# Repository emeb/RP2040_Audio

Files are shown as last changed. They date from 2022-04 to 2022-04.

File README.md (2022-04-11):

# RP2040_Audio
A Eurorack module for stereo audio effects based on the Raspberry Pi RP2040 MCU

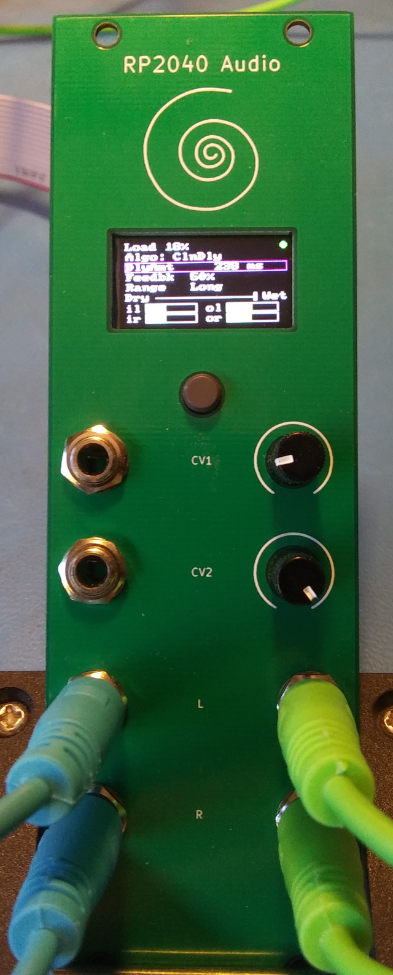
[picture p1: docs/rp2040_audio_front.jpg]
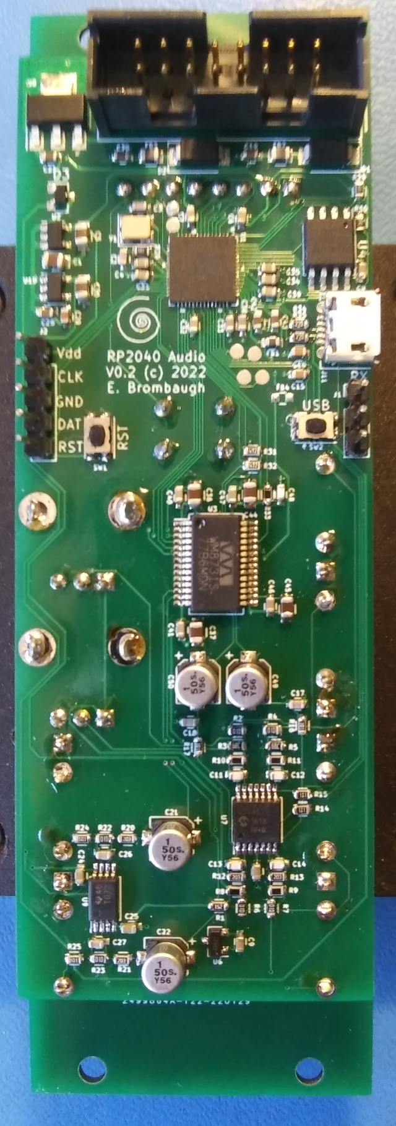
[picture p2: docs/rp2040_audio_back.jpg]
  

## Abstract
I've been doing audio synthesis and effects in the Eurorack modular market for
a number of years. I started out in the late 2000's using the Microchip dsPIC
and migrated over to ARM Cortex M devices, mostly STM32 in order to get access
to higher speeds, more memory and floating point math. This was my main
platform for most of the 2010's until the great silicon drought of the 2020's
made high-end STM32 devices almost impossible to get. Into the vacuum stepped
the good folks at the Raspberry Pi Foundation with the RP2040 MCU which has
a fair chunk of on-chip SRAM, dual ARM Cortex M0 cores and a decent complement
of peripherals.

This project is a feasibility study of using the RP2040 MCU as an audio effects
processor, with particular emphasis on performance with challenging DSP.

## Hardware
The complete design consists of two PCBs:
* The system PCB - a single board containg all electrical components. Find it
in the Hardware directory.
* The Front Panel - a PCB-based front panel that conforms to the Eurorack
physical mounting standard. Found in the Hardware/audio_panel directory.

The system PCB has the following features:
* Standard Eurorack 16-pin shrouded power connector
* Two +/-5V CV inputs and associated analog signal conditioning 
* Two +/-7V Audio inputs and associated analog signal conditioning 
* Two +/-7V Audio outputs and associated analog drivers
* WM8731 stereo audio codec
* RP2040 and 4MB SPI flash with USB, SWD and serial interfaces for development
* 160 x 80 IPS LCD
* UI button

## Firmware
A demonstration firmware is included that exercises all of the capabilities of
the system, including the LCD, UI button, CV inputs and stereo audio I/O. It is
a basic multi-effects unit that supports a complement of audio DSP algorithms
that are easily extended by adding standardized modules to a data structure.
As provided here just three algorithms are available:
* Simple pass-thru with no processing
* Simple gain control
* Basic "clean delay" with crossfaded deglitching during delay changes.

Other algorithms have been tested including phasers, flangers, frequency shifters,
resampling delays and reverbs, but these are not publicly released at this time.

## Findings
Overall the RP2040 is a capable device that can do a reasonable amount of audio
DSP. The lack of floating point is not a huge incovenience if one is handy with
fixed point arithmetic and the large on-chip SRAM is sufficiently large for
reasonable audio data buffers. The PIO is handy for building interfaces and is
capable of full-duplex I2S with no difficulty. The on-chip ADC underperforms its
12-bit data width however and requires a fair bit of post-processing to remove
noise and jitter in the conversion results. The dual ARM cores are useful in
dividing up user interface and DSP tasks to keep a snappy response, but even
with two cores the system struggles to compete with higher-spec ARM systems.

TL;DR - you can use it for DSP, but I'd prefer a Cortex M7.

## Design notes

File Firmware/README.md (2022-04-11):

# RP2040 Audio Firmware
This directory contains the source and build scripts for the RP2040 Audio
firmware.

## Features
* Simple graphic user interface for selecting and controlling a variety
of audio DSP algorithms.
* Single button and CV navigation through availble effects and settings.
* Non-volatile storage of effects parameters so user settings will survive
power cycling and restore to the previous configuration.
* Storage "pending" indicator.
* CPU Load meter to indicate how hard the system is working.
* Wet/Dry mix indicator.
* Independent input/output VU meters for both channels.

## Usage
* System shows splash screen with version number at power-up.
* Use the single button to select which screen parameter to edit. Current
parameter highlighted with a magenta box drawn around it.
* Use CV #1 to edit the parameter. There is hysteresis and 'snap' so that you
must move the CV to begin changing the value from the previous setting.
* CV #2 is dedicated to the Wet/Dry mix.

## Building
This project is built using the Raspberry Pi Pico SDK. 

https://github.com/raspberrypi/pico-sdk

Install the SDK and ensure it's working properly, then within this directory

```shell
mkdir build
cd build
cmake ..
make
```

Then either upload the .uf2 file to the RP2040 via USB, or use SWD to install
the .elf file.

## Acknowledgements
Big thanks to Jonathan Brodsky who provided a great starting point for the
full-duplex I2S I used here. Find his github here:

https://github.com/jonbro

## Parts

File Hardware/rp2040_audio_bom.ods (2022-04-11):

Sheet: rp2040_audio
Source: | /home/ericb/KBADC/kicad/rp2040_audio/rp2040_audio.sch
Date: | Mon 21 Feb 2022 11:02:30 AM MST
Tool: | Eeschema 5.1.12-1.fc34
Generator: | /usr/share/kicad/plugins/bom_csv_grouped_by_value.py
Component Count: | 114
Individual Components:
Item | Qty | Reference(s) | Value | LibPart | Footprint | Datasheet
 |  | C1 | 10uf | Device:C_Small | Capacitors_SMD:C_0805 | ~
 |  | C2 | 27pf | Device:C_Small | Capacitors_SMD:C_0603 | ~
 |  | C3 | 27pf | Device:C_Small | Capacitors_SMD:C_0603 | ~
 |  | C4 | 0.1uf | Device:C_Small | Capacitors_SMD:C_0603 | ~
 |  | C5 | 10uf | Device:C_Small | Capacitors_SMD:C_0805 | ~
 |  | C6 | 0.1uf | Device:C_Small | Capacitors_SMD:C_0603 | ~
 |  | C7 | 0.1uf | Device:C_Small | Capacitors_SMD:C_0603 | ~
 |  | C8 | 0.1uf | Device:C_Small | Capacitors_SMD:C_0603 | ~
 |  | C9 | 0.1uf | Device:C_Small | Capacitors_SMD:C_0603 | ~
 |  | C10 | 0.1uf | Device:C_Small | Capacitors_SMD:C_0603 | ~
 |  | C11 | 330pf | Device:C_Small | Capacitors_SMD:C_0603 | ~
 |  | C12 | 330pf | Device:C_Small | Capacitors_SMD:C_0603 | ~
 |  | C13 | 330pf | Device:C_Small | Capacitors_SMD:C_0603 | ~
 |  | C14 | 330pf | Device:C_Small | Capacitors_SMD:C_0603 | ~
 |  | C15 | 0.01uf | Device:C_Small | Capacitors_SMD:C_0603 | ~
 |  | C16 | 0.01uf | Device:C_Small | Capacitors_SMD:C_0603 | ~
 |  | C17 | 220pf | Device:C_Small | Capacitors_SMD:C_0603 | ~
 |  | C18 | 220pf | Device:C_Small | Capacitors_SMD:C_0603 | ~
 |  | C19 | 1uf | Device:C_Small | Capacitors_SMD:C_0603 | ~
 |  | C20 | 1uf | Device:C_Small | Capacitors_SMD:C_0603 | ~
 |  | C21 | 1uf | Device:CP1 | Capacitors_SMD:CP_Elec_4x5.3 | ~
 |  | C22 | 1uf | Device:CP1 | Capacitors_SMD:CP_Elec_4x5.3 | ~
 |  | C23 | 1uf | Device:C_Small | Capacitors_SMD:C_0603 | ~
 |  | C24 | 0.1uf | Device:C_Small | Capacitors_SMD:C_0603 | ~
 |  | C25 | 0.1uf | Device:C_Small | Capacitors_SMD:C_0603 | ~
 |  | C26 | 68pf | Device:C_Small | Capacitors_SMD:C_0603 | ~
 |  | C27 | 68pf | Device:C_Small | Capacitors_SMD:C_0603 | ~
 |  | C28 | 1uf | Device:C_Small | Capacitors_SMD:C_0603 | ~
 |  | C29 | 0.01uf | Device:C_Small | Capacitors_SMD:C_0603 | ~
 |  | C30 | 10uf | Device:C_Small | Capacitors_SMD:C_0805 | ~
 |  | C31 | 0.1uf | Device:C_Small | Capacitors_SMD:C_0603 | ~
 |  | C32 | 0.1uf | Device:C_Small | Capacitors_SMD:C_0603 | ~
 |  | C33 | 0.1uf | Device:C_Small | Capacitors_SMD:C_0603 | ~
 |  | C34 | 0.1uf | Device:C_Small | Capacitors_SMD:C_0603 | ~
 |  | C35 | 0.1uf | Device:C_Small | Capacitors_SMD:C_0603 | ~
 |  | C36 | 10uf | Device:C_Small | Capacitors_SMD:C_0805 | ~
 |  | C37 | 10uf | Device:C_Small | Capacitors_SMD:C_0805 | ~
 |  | C38 | 0.1uf | Device:C_Small | Capacitors_SMD:C_0603 | ~
 |  | C39 | 0.1uf | Device:C_Small | Capacitors_SMD:C_0603 | ~
 |  | C40 | 0.1uf | Device:C_Small | Capacitors_SMD:C_0603 | ~
 |  | C41 | 0.1uf | Device:C_Small | Capacitors_SMD:C_0603 | ~
 |  | C42 | 1uf | Device:C_Small | Capacitors_SMD:C_0603 | ~
 |  | C43 | 1uf | Device:C_Small | Capacitors_SMD:C_0603 | ~
 |  | C44 | 10uf | Device:C_Small | Capacitors_SMD:C_0805 | ~
 |  | C45 | 10uf | Device:C_Small | Capacitors_SMD:C_0805 | ~
 |  | C46 | 0.1uf | Device:C_Small | Capacitors_SMD:C_0603 | ~
 |  | C47 | 0.1uf | Device:C_Small | Capacitors_SMD:C_0603 | ~
 |  | C48 | 330pf | Device:C_Small | Capacitors_SMD:C_0603 | ~
 |  | C49 | 1uf | Device:CP1 | Capacitors_SMD:CP_Elec_4x5.3 | ~
 |  | C50 | 1uf | Device:CP1 | Capacitors_SMD:CP_Elec_4x5.3 | ~
 |  | D1 | D | Device:D | Diodes_SMD:D_SMA | ~
 |  | D2 | D | Device:D | Diodes_SMD:D_SMA | ~
 |  | D3 | BAT54C | Diode:BAT54C | Package_TO_SOT_SMD:SOT-23 | http://www.diodes.com/_files/datasheets/ds11005.pdf
 |  | FB1 | 1k | Device:Ferrite_Bead_Small | Capacitors_SMD:C_0603 | ~
 |  | FB2 | 220 | Device:Ferrite_Bead_Small | Resistors_SMD:R_0805 | ~
 |  | FB3 | 220 | Device:Ferrite_Bead_Small | Resistors_SMD:R_0805 | ~
 |  | FB4 | 1k | Device:Ferrite_Bead_Small | Capacitors_SMD:C_0603 | ~
 |  | J1 | Serial | Connector_Generic:Conn_01x03 | Pin_Headers:Pin_Header_Straight_1x03_Pitch2.54mm | ~
 |  | J2 | SWD | Connector_Generic:Conn_01x05 | Pin_Headers:Pin_Header_Straight_1x05_Pitch2.54mm | ~
 |  | J3 | LCD | Connector_Generic:Conn_01x08 | footprints:LCD_80x160_0.96 | ~
 |  | J4 | AudioJack2_SwitchT | Connector:AudioJack2_SwitchT | footprints:Jack_3.5mm_QingPu_WQP-PJ398SM_Vertical_CircularHoles | ~
 |  | J5 | AudioJack2_SwitchT | Connector:AudioJack2_SwitchT | footprints:Jack_3.5mm_QingPu_WQP-PJ398SM_Vertical_CircularHoles | ~
 |  | J6 | AudioJack2_SwitchT | Connector:AudioJack2_SwitchT | footprints:Jack_3.5mm_QingPu_WQP-PJ398SM_Vertical_CircularHoles | ~
 |  | J7 | AudioJack2_SwitchT | Connector:AudioJack2_SwitchT | footprints:Jack_3.5mm_QingPu_WQP-PJ398SM_Vertical_CircularHoles | ~
 |  | J8 | Conn_02x08_Odd_Even | Connector_Generic:Conn_02x08_Odd_Even | footprints:5103308-3 | ~
 |  | J9 | AudioJack2_SwitchT | Connector:AudioJack2_SwitchT | footprints:Jack_3.5mm_QingPu_WQP-PJ398SM_Vertical_CircularHoles | ~
 |  | J10 | AudioJack2_SwitchT | Connector:AudioJack2_SwitchT | footprints:Jack_3.5mm_QingPu_WQP-PJ398SM_Vertical_CircularHoles | ~
 |  | J11 | USB_B_Micro | Connector:USB_B_Micro | footprints:USB_Micro-B_10103594-0001LF_actual_outline | ~
 |  | R1 | 1.5k | Device:R | Resistors_SMD:R_0603 | ~
 |  | R2 | 100k | Device:R | Resistors_SMD:R_0603 | ~
 |  | R3 | 49.9k | Device:R | Resistors_SMD:R_0603 | ~
 |  | R4 | 100k | Device:R | Resistors_SMD:R_0603 | ~
 |  | R5 | 49.9k | Device:R | Resistors_SMD:R_0603 | ~
 |  | R6 | 100k | Device:R | Resistors_SMD:R_0603 | ~
 |  | R7 | 100k | Device:R | Resistors_SMD:R_0603 | ~
 |  | R8 | 60.4k | Device:R | Resistors_SMD:R_0603 | ~
 |  | R9 | 60.4k | Device:R | Resistors_SMD:R_0603 | ~
 |  | R10 | 33k | Device:R | Resistors_SMD:R_0603 | ~
 |  | R11 | 33k | Device:R | Resistors_SMD:R_0603 | ~
 |  | R12 | 20k | Device:R | Resistors_SMD:R_0603 | ~
 |  | R13 | 20k | Device:R | Resistors_SMD:R_0603 | ~
 |  | R14 | 180 | Device:R | Resistors_SMD:R_0603 | ~
 |  | R15 | 180 | Device:R | Resistors_SMD:R_0603 | ~
 |  | R16 | 100 | Device:R | Resistors_SMD:R_0603 | ~
 |  | R17 | 100 | Device:R | Resistors_SMD:R_0603 | ~
 |  | R20 | 20k | Device:R | Resistors_SMD:R_0603 | ~
 |  | R21 | 20k | Device:R | Resistors_SMD:R_0603 | ~
 |  | R22 | 100k | Device:R | Resistors_SMD:R_0603 | ~
 |  | R23 | 100k | Device:R | Resistors_SMD:R_0603 | ~
 |  | R24 | 100 | Device:R | Resistors_SMD:R_0603 | ~
 |  | R25 | 100 | Device:R | Resistors_SMD:R_0603 | ~
 |  | R28 | 1k | Device:R | Resistors_SMD:R_0603 | ~
 |  | R29 | 10k | Device:R | Resistors_SMD:R_0603 | ~
 |  | R30 | 1k | Device:R | Resistors_SMD:R_0603 | ~
 |  | R31 | 4.7k | Device:R | Resistors_SMD:R_0603 | ~
 |  | R32 | 4.7k | Device:R | Resistors_SMD:R_0603 | ~
 |  | R33 | 49 | Device:R | Resistors_SMD:R_0603 | ~
 |  | R34 | 27.5 | Device:R | Resistors_SMD:R_0603 | ~
 |  | R35 | 27.5 | Device:R | Resistors_SMD:R_0603 | ~
 |  | RV1 | 10k | Device:R_POT | footprints:Potentiometer_TT_P0915N | ~
 |  | RV2 | 10k | Device:R_POT | footprints:Potentiometer_TT_P0915N | ~
 |  | SW1 | SW_Push | Switch:SW_Push | Buttons_Switches_SMD:SW_SPST_KMR2 | ~
 |  | SW2 | SW_Push | Switch:SW_Push | Buttons_Switches_SMD:SW_SPST_KMR2 | ~
 |  | SW4 | SW_Push | Switch:SW_Push | footprints:SW_PUSH_6mm_Center | ~
 |  | U1 | RP2040 | emeb_library:RP2040 | footprints:RP2040
 |  | U2 | MCP1802x-xx02xOT | Regulator_Linear:MCP1802x-xx02xOT | TO_SOT_Packages_SMD:SOT-23-5 | http://ww1.microchip.com/downloads/en/DeviceDoc/22053C.pdf
 |  | U3 | WM8731 | emeb_library:WM8731 | Housings_SSOP:SSOP-28_5.3x10.2mm_Pitch0.65mm
 |  | U4 | W25Q32JVSS | Memory_Flash:W25Q32JVSS | Package_SO:SOIC-8_5.23x5.23mm_P1.27mm | http://www.winbond.com/resource-files/w25q32jv%20revg%2003272018%20plus.pdf
 |  | U6 | LM4040DBZ-5 | Reference_Voltage:LM4040DBZ-5 | Package_TO_SOT_SMD:SOT-23 | http://www.ti.com/lit/ds/symlink/lm4040-n.pdf
 |  | U7 | MCP6004 | Amplifier_Operational:MCP6004 | Housings_SSOP:TSSOP-14_4.4x5mm_Pitch0.65mm | http://www.ti.com/lit/ds/symlink/tl081.pdf
 |  | U8 | LM1117-5.0 | Regulator_Linear:LM1117-5.0 | TO_SOT_Packages_SMD:SOT-223-3_TabPin2 | http://www.ti.com/lit/ds/symlink/lm1117.pdf
 |  | U9 | TL072PW | Amplifier_Operational:TL082 | Housings_SSOP:TSSOP-8_4.4x3mm_Pitch0.65mm | http://www.ti.com/lit/ds/symlink/tl081.pdf
 |  | U10 | LP2985-3.3 | Regulator_Linear:LP2985-3.3 | TO_SOT_Packages_SMD:SOT-23-5 | http://www.ti.com/lit/ds/symlink/lp2985.pdf
 |  | Y1 | Crystal_4pin_SMD | emeb_library:Crystal_4pin_SMD | Crystals:Crystal_SMD_3225-4pin_3.2x2.5mm
Collated Components:
Item | Qty | Reference(s) | Value | LibPart | Footprint | Datasheet
1 | 7 | C1, C5, C30, C36, C37, C44, C45 | 10uf | Device:C_Small | Capacitors_SMD:C_0805 | ~
2 | 2 | C2, C3 | 27pf | Device:C_Small | Capacitors_SMD:C_0603 | ~
3 | 19 | C4, C6, C7, C8, C9, C10, C24, C25, C31, C32, C33, C34, C35, C38, C39, C40, C41, C46, C47 | 0.1uf | Device:C_Small | Capacitors_SMD:C_0603 | ~
4 | 5 | C11, C12, C13, C14, C48 | 330pf | Device:C_Small | Capacitors_SMD:C_0603 | ~
5 | 3 | C15, C16, C29 | 0.01uf | Device:C_Small | Capacitors_SMD:C_0603 | ~
6 | 2 | C17, C18 | 220pf | Device:C_Small | Capacitors_SMD:C_0603 | ~
7 | 6 | C19, C20, C23, C28, C42, C43 | 1uf | Device:C_Small | Capacitors_SMD:C_0603 | ~
8 | 4 | C21, C22, C49, C50 | 1uf | Device:CP1 | Capacitors_SMD:CP_Elec_4x5.3 | ~
9 | 2 | C26, C27 | 68pf | Device:C_Small | Capacitors_SMD:C_0603 | ~
10 | 2 | D1, D2 | D | Device:D | Diodes_SMD:D_SMA | ~
11 | 1 | D3 | BAT54C | Diode:BAT54C | Package_TO_SOT_SMD:SOT-23 | http://www.diodes.com/_files/datasheets/ds11005.pdf
12 | 2 | FB1, FB4 | 1k | Device:Ferrite_Bead_Small | Capacitors_SMD:C_0603 | ~
13 | 2 | FB2, FB3 | 220 | Device:Ferrite_Bead_Small | Resistors_SMD:R_0805 | ~
14 | 1 | J1 | Serial | Connector_Generic:Conn_01x03 | Pin_Headers:Pin_Header_Straight_1x03_Pitch2.54mm | ~
15 | 1 | J2 | SWD | Connector_Generic:Conn_01x05 | Pin_Headers:Pin_Header_Straight_1x05_Pitch2.54mm | ~
16 | 1 | J3 | LCD | Connector_Generic:Conn_01x08 | footprints:LCD_80x160_0.96 | ~
17 | 6 | J4, J5, J6, J7, J9, J10 | AudioJack2_SwitchT | Connector:AudioJack2_SwitchT | footprints:Jack_3.5mm_QingPu_WQP-PJ398SM_Vertical_CircularHoles | ~
18 | 1 | J8 | Conn_02x08_Odd_Even | Connector_Generic:Conn_02x08_Odd_Even | footprints:5103308-3 | ~
19 | 1 | J11 | USB_B_Micro | Connector:USB_B_Micro | footprints:USB_Micro-B_10103594-0001LF_actual_outline | ~
20 | 1 | R1 | 1.5k | Device:R | Resistors_SMD:R_0603 | ~
21 | 6 | R2, R4, R6, R7, R22, R23 | 100k | Device:R | Resistors_SMD:R_0603 | ~
22 | 2 | R3, R5 | 49.9k | Device:R | Resistors_SMD:R_0603 | ~
23 | 2 | R8, R9 | 60.4k | Device:R | Resistors_SMD:R_0603 | ~
24 | 2 | R10, R11 | 33k | Device:R | Resistors_SMD:R_0603 | ~
25 | 4 | R12, R13, R20, R21 | 20k | Device:R | Resistors_SMD:R_0603 | ~
26 | 2 | R14, R15 | 180 | Device:R | Resistors_SMD:R_0603 | ~
27 | 4 | R16, R17, R24, R25 | 100 | Device:R | Resistors_SMD:R_0603 | ~
28 | 2 | R28, R30 | 1k | Device:R | Resistors_SMD:R_0603 | ~
29 | 1 | R29 | 10k | Device:R | Resistors_SMD:R_0603 | ~
30 | 2 | R31, R32 | 4.7k | Device:R | Resistors_SMD:R_0603 | ~
31 | 1 | R33 | 49 | Device:R | Resistors_SMD:R_0603 | ~
32 | 2 | R34, R35 | 27.5 | Device:R | Resistors_SMD:R_0603 | ~
33 | 2 | RV1, RV2 | 10k | Device:R_POT | footprints:Potentiometer_TT_P0915N | ~
34 | 2 | SW1, SW2 | SW_Push | Switch:SW_Push | Buttons_Switches_SMD:SW_SPST_KMR2 | ~
35 | 1 | SW4 | SW_Push | Switch:SW_Push | footprints:SW_PUSH_6mm_Center | ~
36 | 1 | U1 | RP2040 | emeb_library:RP2040 | footprints:RP2040
37 | 1 | U2 | MCP1802x-xx02xOT | Regulator_Linear:MCP1802x-xx02xOT | TO_SOT_Packages_SMD:SOT-23-5 | http://ww1.microchip.com/downloads/en/DeviceDoc/22053C.pdf
38 | 1 | U3 | WM8731 | emeb_library:WM8731 | Housings_SSOP:SSOP-28_5.3x10.2mm_Pitch0.65mm
39 | 1 | U4 | W25Q32JVSS | Memory_Flash:W25Q32JVSS | Package_SO:SOIC-8_5.23x5.23mm_P1.27mm | http://www.winbond.com/resource-files/w25q32jv%20revg%2003272018%20plus.pdf
40 | 1 | U6 | LM4040DBZ-5 | Reference_Voltage:LM4040DBZ-5 | Package_TO_SOT_SMD:SOT-23 | http://www.ti.com/lit/ds/symlink/lm4040-n.pdf
41 | 1 | U7 | MCP6004 | Amplifier_Operational:MCP6004 | Housings_SSOP:TSSOP-14_4.4x5mm_Pitch0.65mm | http://www.ti.com/lit/ds/symlink/tl081.pdf
42 | 1 | U8 | LM1117-5.0 | Regulator_Linear:LM1117-5.0 | TO_SOT_Packages_SMD:SOT-223-3_TabPin2 | http://www.ti.com/lit/ds/symlink/lm1117.pdf
43 | 1 | U9 | TL072PW | Amplifier_Operational:TL082 | Housings_SSOP:TSSOP-8_4.4x3mm_Pitch0.65mm | http://www.ti.com/lit/ds/symlink/tl081.pdf
44 | 1 | U10 | LP2985-3.3 | Regulator_Linear:LP2985-3.3 | TO_SOT_Packages_SMD:SOT-23-5 | http://www.ti.com/lit/ds/symlink/lp2985.pdf
45 | 1 | Y1 | Crystal_4pin_SMD | emeb_library:Crystal_4pin_SMD | Crystals:Crystal_SMD_3225-4pin_3.2x2.5mm

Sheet: Sheet2
Item | Qty | Reference(s) | Value | LibPart
1 | 7 | C1, C5, C30, C36, C37, C44, C45 | 10uf | Device:C_Small
2 | 2 | C2, C3 | 27pf | Device:C_Small
3 | 19 | C4, C6, C7, C8, C9, C10, C24, C25, C31, C32, C33, C34, C35, C38, C39, C40, C41, C46, C47 | 0.1uf | Device:C_Small
4 | 5 | C11, C12, C13, C14, C48 | 330pf | Device:C_Small
5 | 3 | C15, C16, C29 | 0.01uf | Device:C_Small
6 | 2 | C17, C18 | 220pf | Device:C_Small
7 | 6 | C19, C20, C23, C28, C42, C43 | 1uf | Device:C_Small
8 | 4 | C21, C22, C49, C50 | 1uf | Device:CP1
9 | 2 | C26, C27 | 68pf | Device:C_Small
10 | 2 | D1, D2 | D | Device:D
11 | 1 | D3 | BAT54C | Diode:BAT54C
12 | 2 | FB1, FB4 | 1k | Device:Ferrite_Bead_Small
13 | 2 | FB2, FB3 | 220 | Device:Ferrite_Bead_Small
14 | 1 | J1 | Serial | Connector_Generic:Conn_01x03
15 | 1 | J2 | SWD | Connector_Generic:Conn_01x05
16 | 1 | J3 | LCD | Connector_Generic:Conn_01x08
17 | 6 | J4, J5, J6, J7, J9, J10 | AudioJack2_SwitchT | Connector:AudioJack2_SwitchT
18 | 1 | J8 | Conn_02x08_Odd_Even | Connector_Generic:Conn_02x08_Odd_Even
19 | 1 | J11 | USB_B_Micro | Connector:USB_B_Micro
20 | 1 | R1 | 1.5k | Device:R
21 | 6 | R2, R4, R6, R7, R22, R23 | 100k | Device:R
22 | 2 | R3, R5 | 49.9k | Device:R
23 | 2 | R8, R9 | 60.4k | Device:R
24 | 2 | R10, R11 | 33k | Device:R
25 | 4 | R12, R13, R20, R21 | 20k | Device:R
26 | 2 | R14, R15 | 180 | Device:R
27 | 4 | R16, R17, R24, R25 | 100 | Device:R
28 | 2 | R28, R30 | 1k | Device:R
29 | 1 | R29 | 10k | Device:R
30 | 2 | R31, R32 | 4.7k | Device:R
31 | 1 | R33 | 49 | Device:R
32 | 2 | R34, R35 | 27.5 | Device:R
33 | 2 | RV1, RV2 | 10k | Device:R_POT
34 | 2 | SW1, SW2 | SW_Push | Switch:SW_Push
35 | 1 | SW4 | SW_Push | Switch:SW_Push
36 | 1 | U1 | RP2040 | emeb_library:RP2040
37 | 1 | U2 | MCP1802x-xx02xOT | Regulator_Linear:MCP1802x-xx02xOT
38 | 1 | U3 | WM8731 | emeb_library:WM8731
39 | 1 | U4 | W25Q32JVSS | Memory_Flash:W25Q32JVSS
40 | 1 | U6 | LM4040DBZ-5 | Reference_Voltage:LM4040DBZ-5
41 | 1 | U7 | MCP6004 | Amplifier_Operational:MCP6004
42 | 1 | U8 | LM1117-5.0 | Regulator_Linear:LM1117-5.0
43 | 1 | U9 | TL072PW | Amplifier_Operational:TL082
44 | 1 | U10 | LP2985-3.3 | Regulator_Linear:LP2985-3.3
45 | 1 | Y1 | Crystal_4pin_SMD | emeb_library:Crystal_4pin_SMD

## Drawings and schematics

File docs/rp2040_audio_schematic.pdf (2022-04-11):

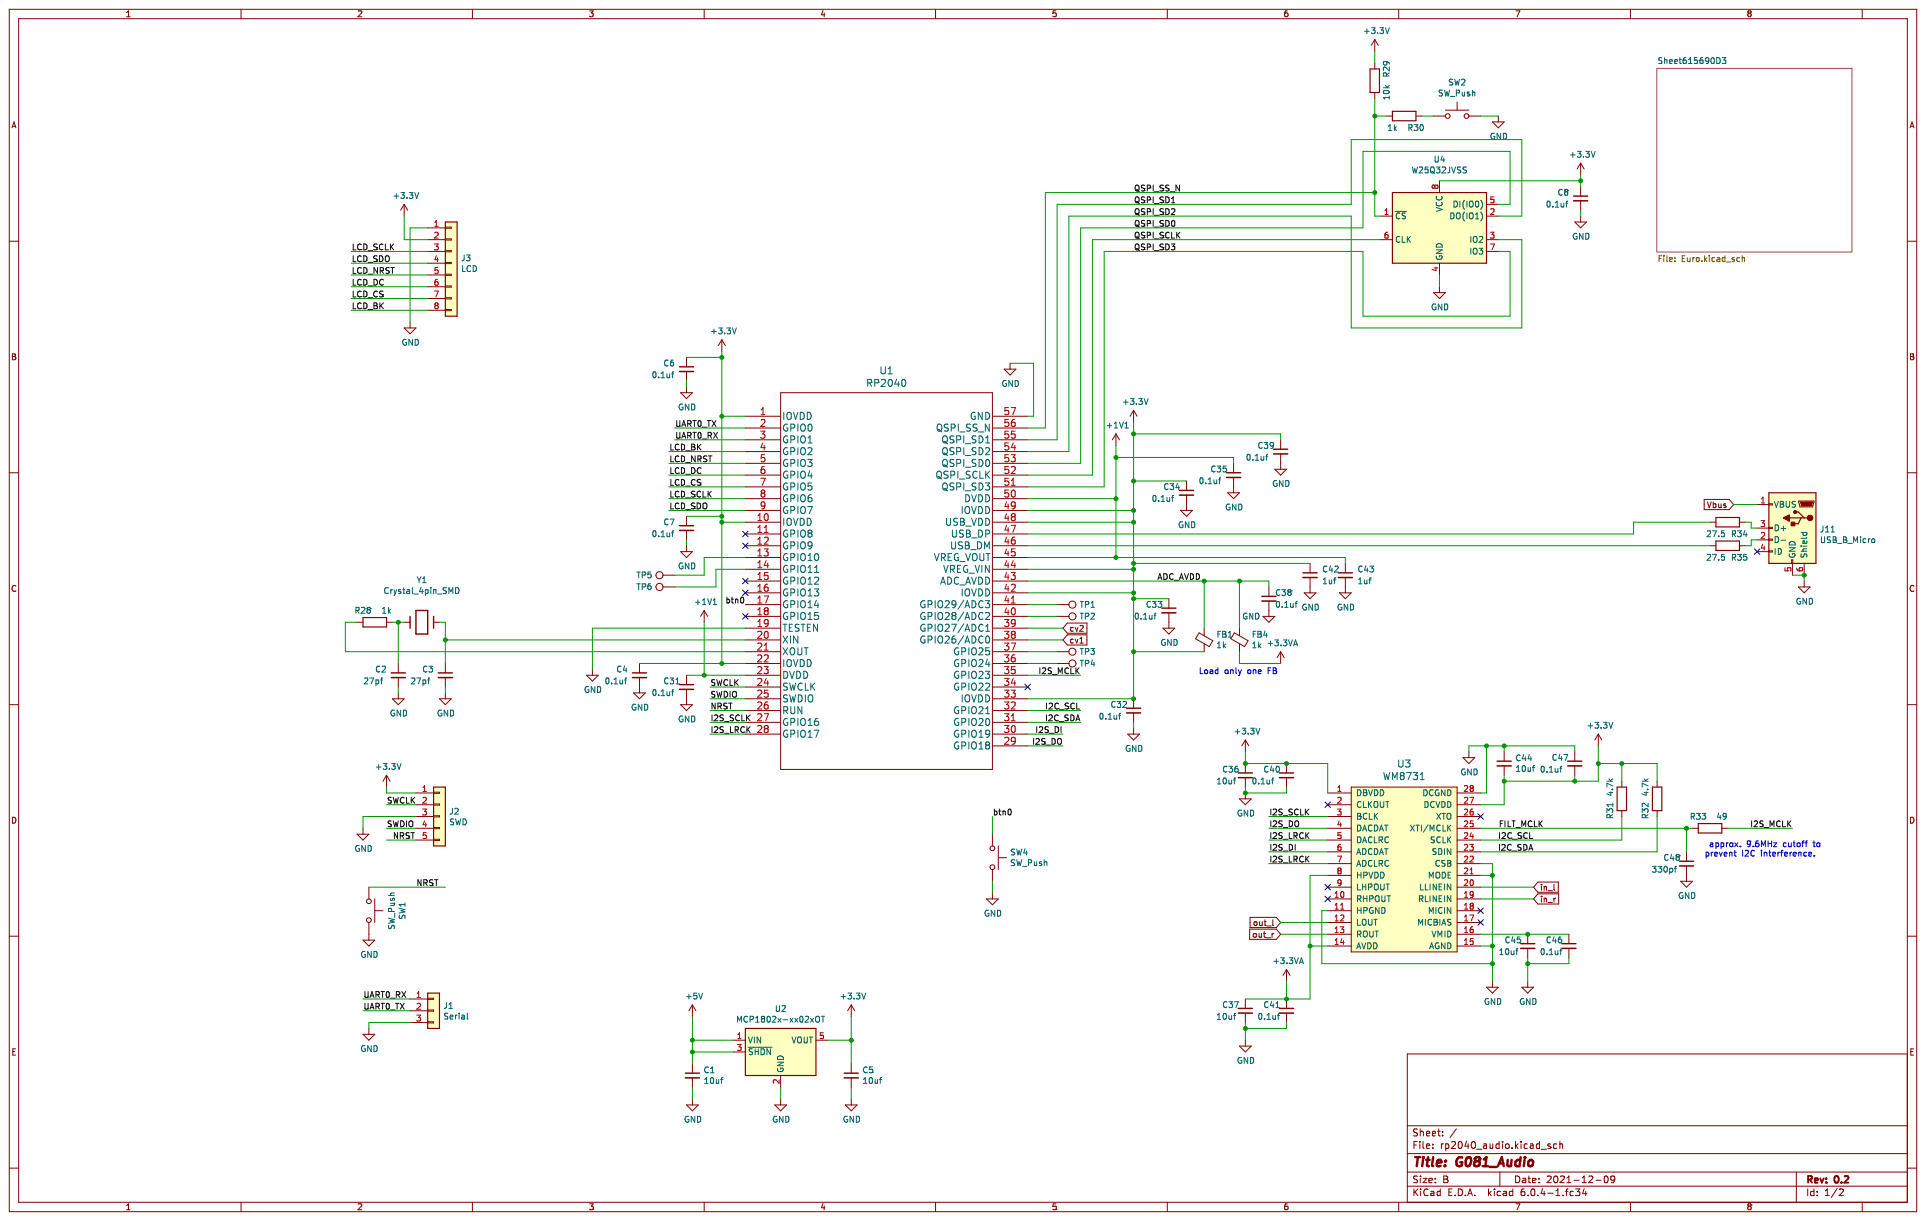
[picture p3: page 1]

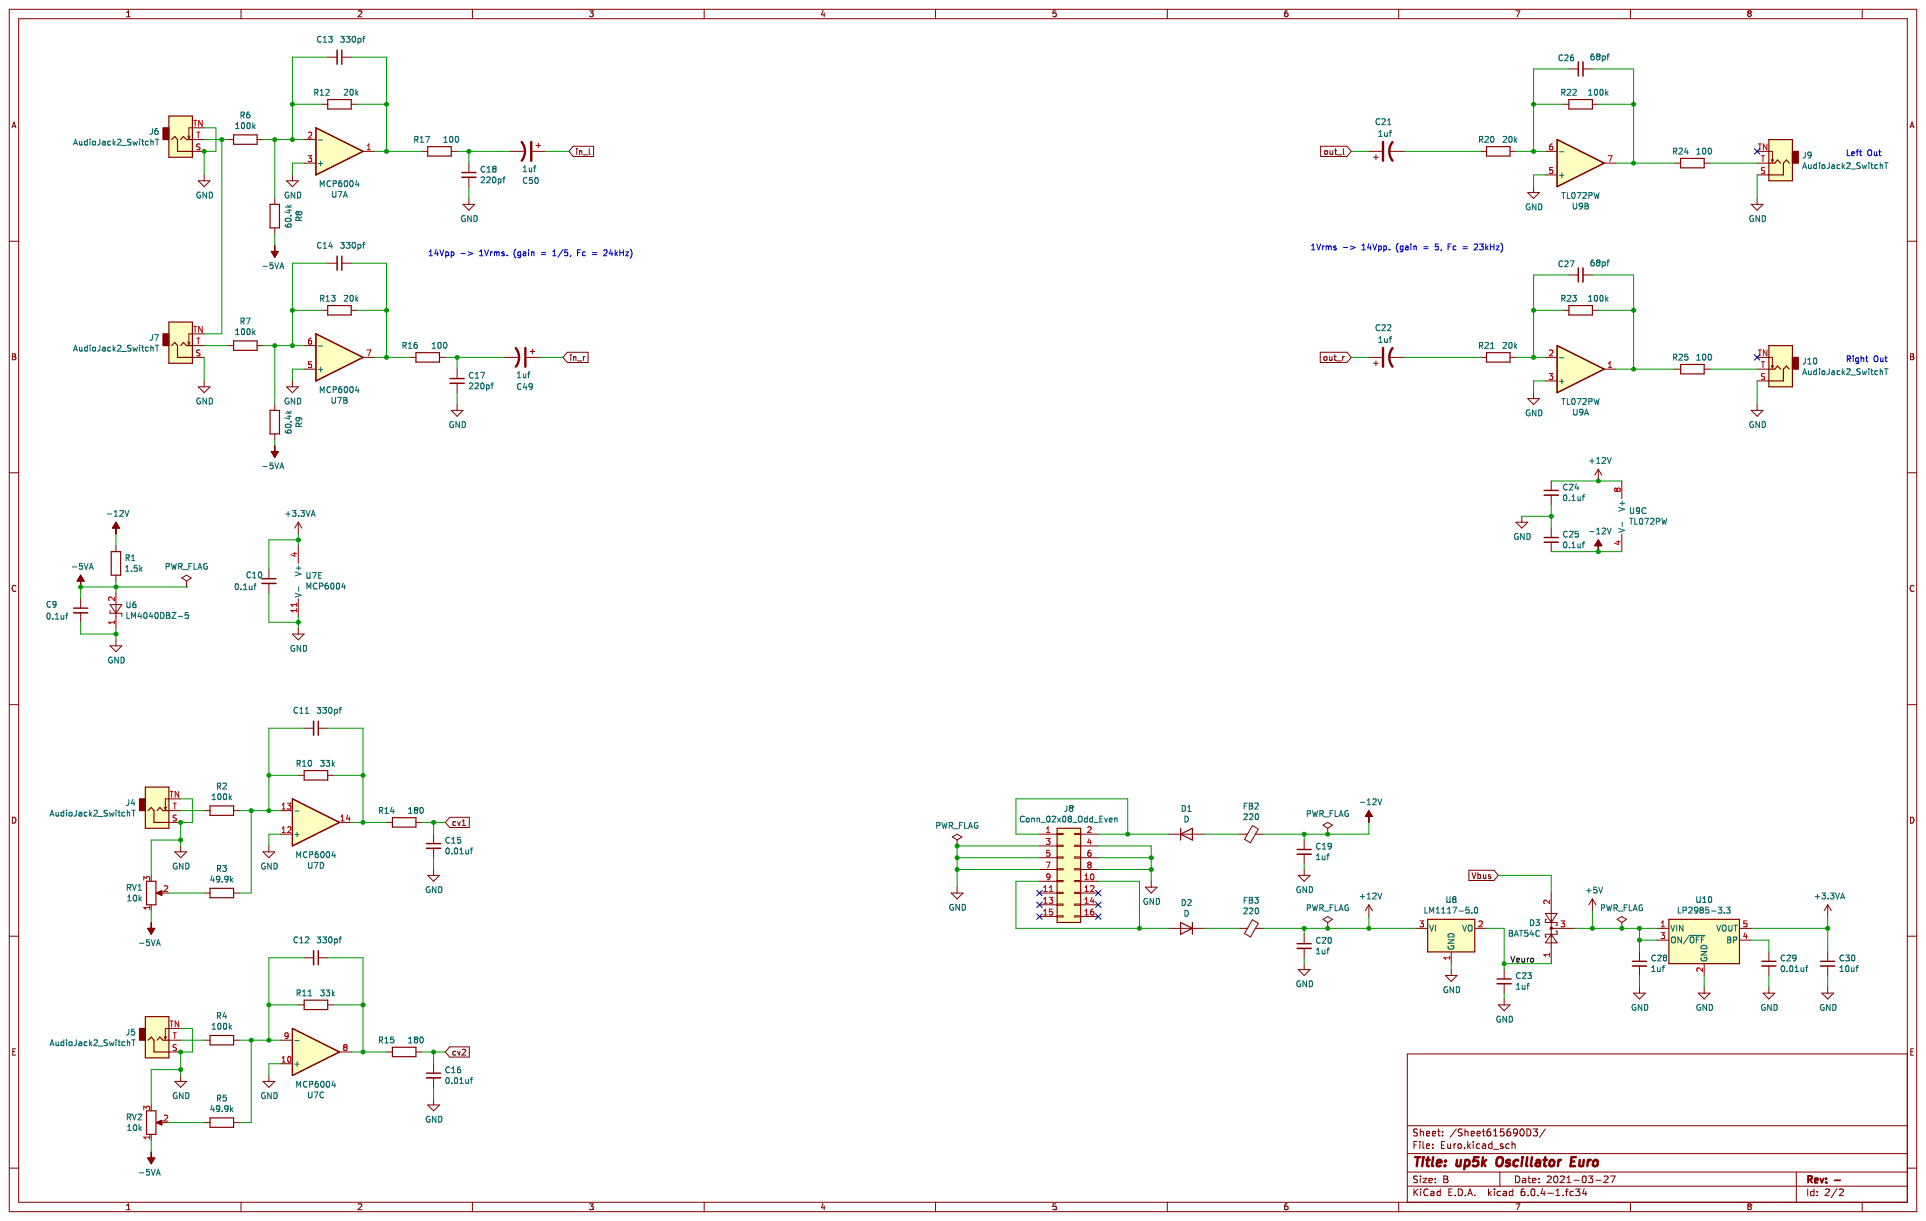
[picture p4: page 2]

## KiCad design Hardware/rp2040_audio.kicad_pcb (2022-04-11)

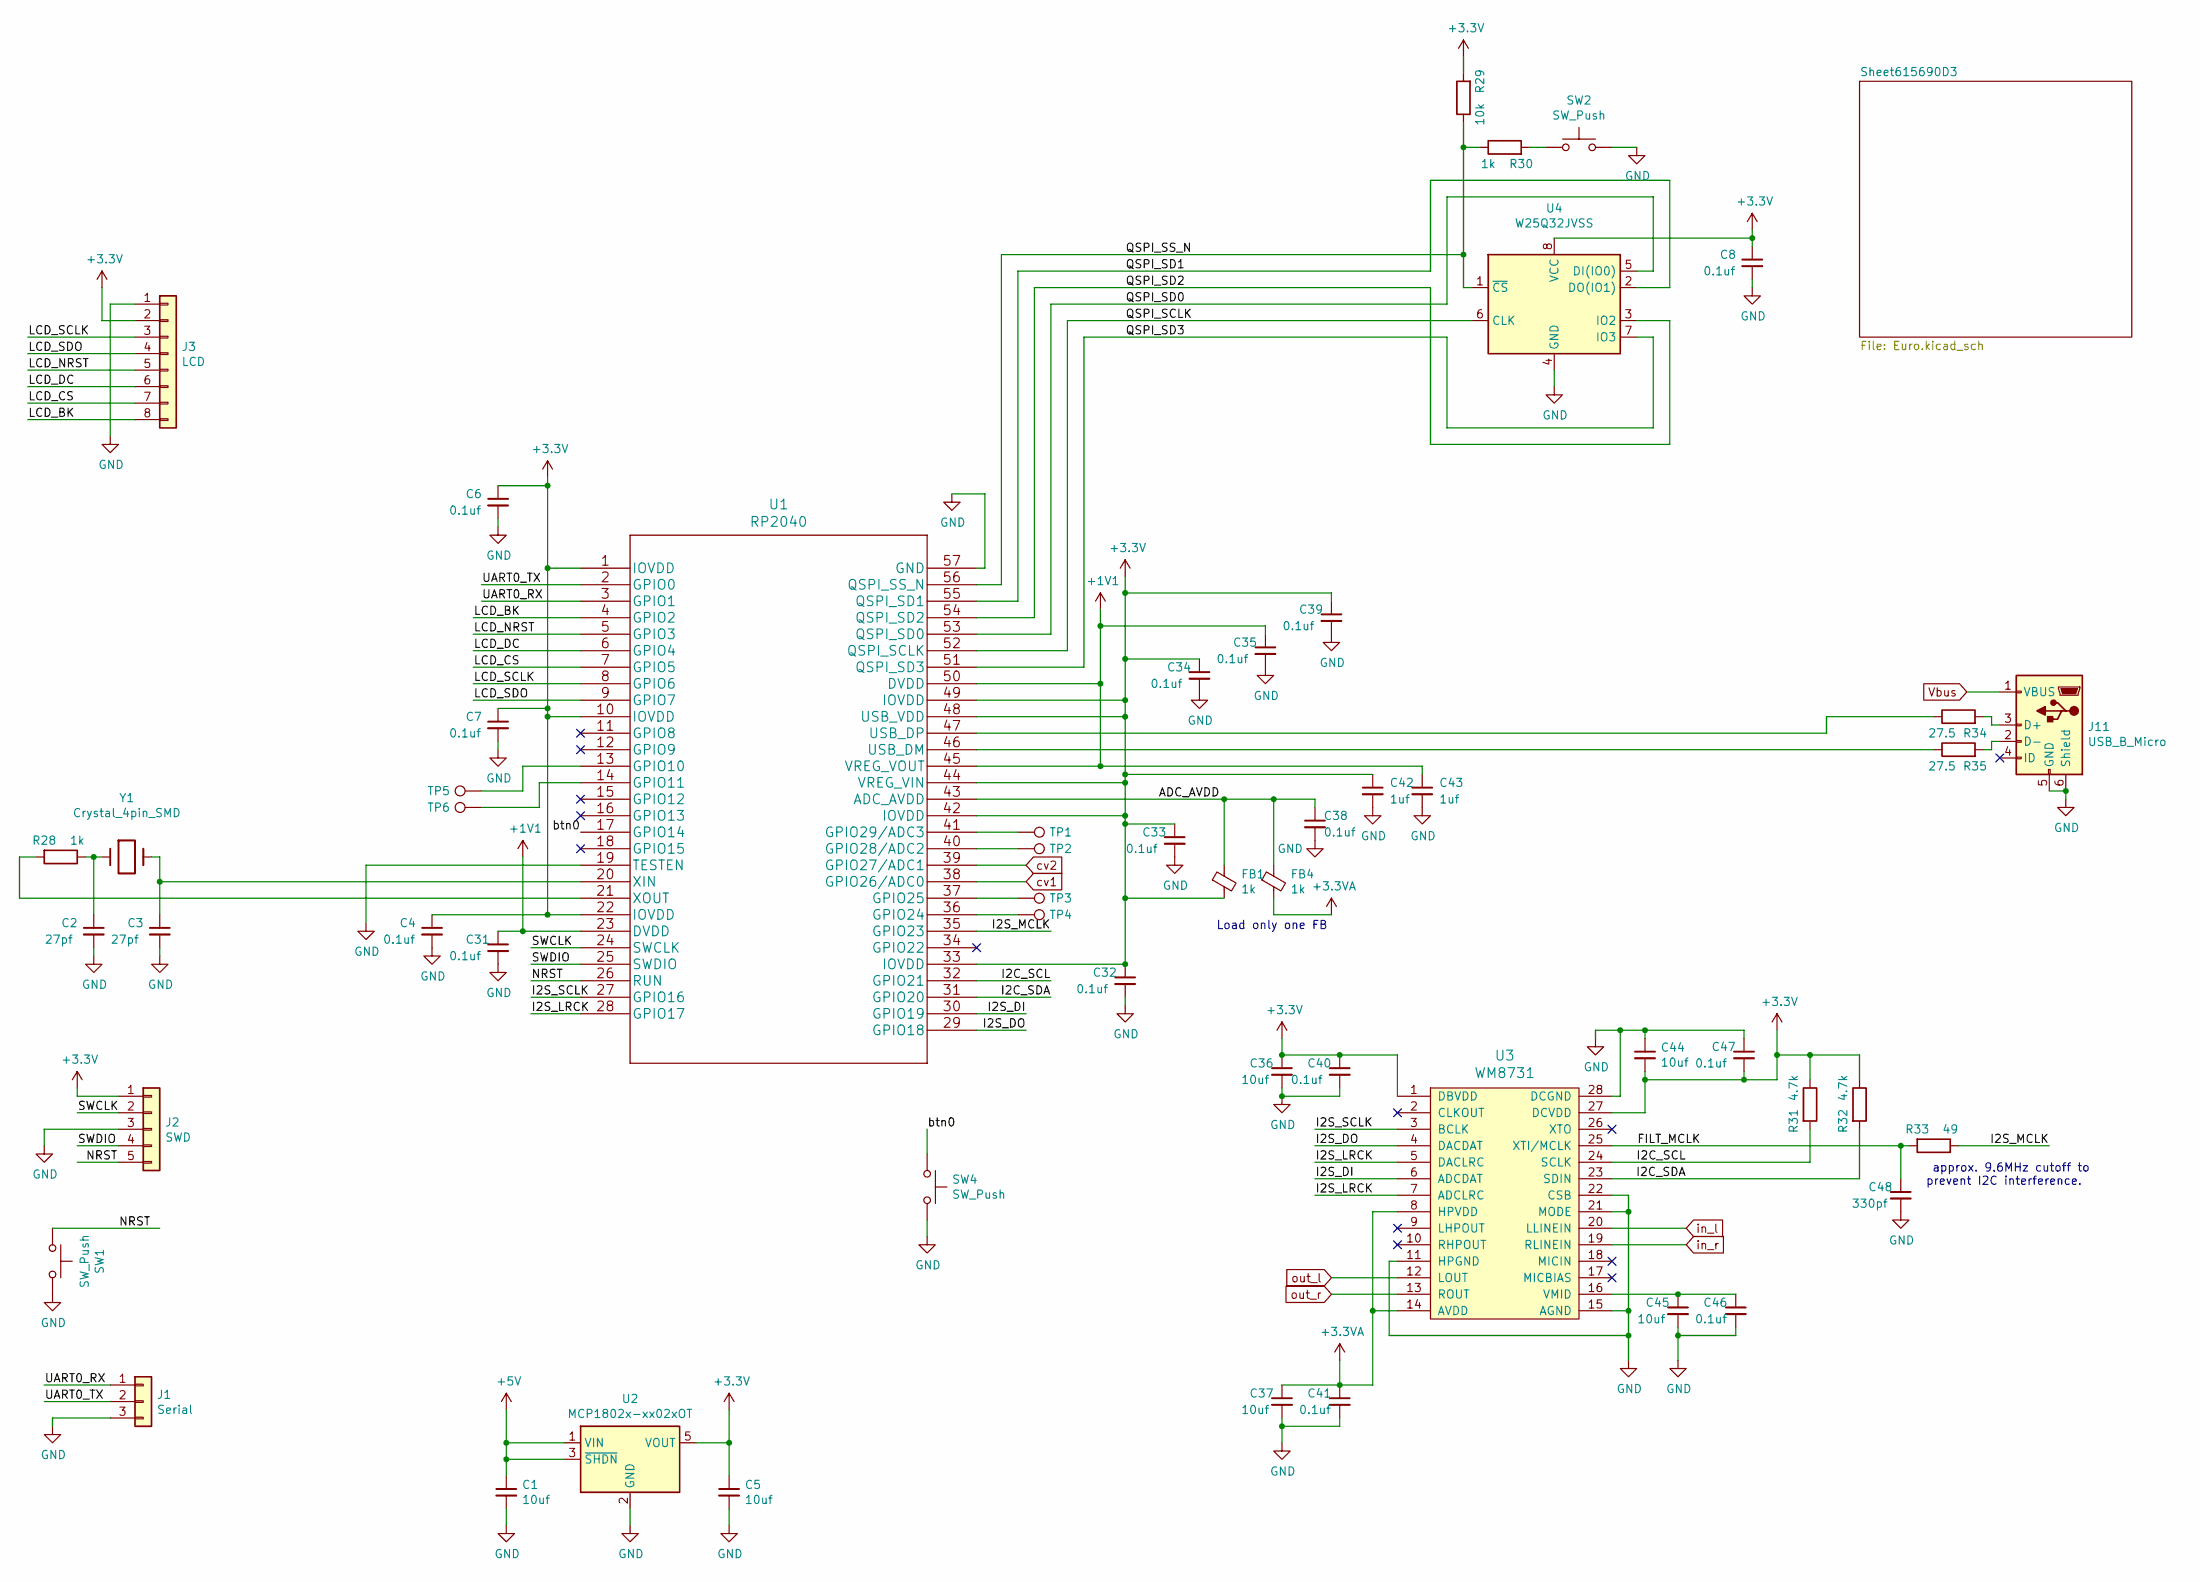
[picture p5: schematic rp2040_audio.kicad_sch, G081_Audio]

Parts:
C1, C5, C36, C37, C44, C45: 10uf; C_0805
C2, C3: 27pf; C_0603
C4, C6, C7, C8, C31, C32, C33, C34, C35, C38, C39, C40, C41, C46, C47: 0.1uf; C_0603
C42, C43: 1uf; C_0603
C48: 330pf; C_0603
FB1, FB4: 1k; C_0603
J1: Serial; Pin_Header_Straight_1x03_Pitch2.54mm
J2: SWD; Pin_Header_Straight_1x05_Pitch2.54mm
J3: LCD; LCD_80x160_0.96
J11: USB_B_Micro; USB_Micro-B_10103594-0001LF_actual_outline
R28, R30: 1k; R_0603
R29: 10k; R_0603
R31, R32: 4.7k; R_0603
R33: 49; R_0603
R34, R35: 27.5; R_0603
SW1, SW2: SW_Push; SW_SPST_KMR2
SW4: SW_Push; SW_PUSH_6mm_Center
TP1, TP2, TP3, TP4, TP5, TP6: TestPoint; Measurement_Point_Round-SMD-Pad_Small
U1: RP2040
U2: MCP1802x-xx02xOT; SOT-23-5
U3: WM8731; SSOP-28_5.3x10.2mm_Pitch0.65mm
U4: W25Q32JVSS; SOIC-8_5.23x5.23mm_P1.27mm
Y1: Crystal_4pin_SMD; Crystal_SMD_3225-4pin_3.2x2.5mm

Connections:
+1V1: C31.1, C35.1, C43.1, U1.23 (DVDD), U1.45 (VREG_VOUT), U1.50 (DVDD)
+3.3VA: C37.1, C41.1, FB4.2, U3.8 (HPVDD), U3.14 (AVDD); also elsewhere on the board
+3V3: C4.1, C5.1, C6.1, C7.1, C8.1, C32.1, C33.1, C34.1, C36.1, C39.1, C40.1, C42.1, C44.2, C47.2, FB1.2, J2.1, J3.2, R29.2, R31.1, R32.1, U1.1 (IOVDD), U1.10 (IOVDD), U1.22 (IOVDD), U1.33 (IOVDD), U1.42 (IOVDD), U1.44 (VREG_VIN), U1.48 (USB_VDD), U1.49 (IOVDD), U2.5 (VOUT), U3.1 (DBVDD), U3.27 (DCVDD), U4.8 (VCC)
+5V: C1.1, U2.1 (VIN), U2.3 (~SHDN); also elsewhere on the board
/ADC_AVDD: C38.1, FB1.1, FB4.1, U1.43 (ADC_AVDD)
/FILT_MCLK: C48.1, R33.2, U3.25 (XTI/MCLK)
/I2C_SCL: R31.2, U1.32 (GPIO21), U3.24 (SCLK)
/I2C_SDA: R32.2, U1.31 (GPIO20), U3.23 (SDIN)
/I2S_DI: U1.30 (GPIO19), U3.6 (ADCDAT)
/I2S_DO: U1.29 (GPIO18), U3.4 (DACDAT)
/I2S_LRCK: U1.28 (GPIO17), U3.5 (DACLRC), U3.7 (ADCLRC)
/I2S_MCLK: R33.1, U1.35 (GPIO23)
/I2S_SCLK: U1.27 (GPIO16), U3.3 (BCLK)
/LCD_BK: J3.8, U1.4 (GPIO2)
/LCD_CS: J3.7, U1.7 (GPIO5)
/LCD_DC: J3.6, U1.6 (GPIO4)
/LCD_NRST: J3.5, U1.5 (GPIO3)
/LCD_SCLK: J3.3, U1.8 (GPIO6)
/LCD_SDO: J3.4, U1.9 (GPIO7)
/NRST: J2.5, SW1.1, U1.26 (RUN)
/QSPI_SCLK: U1.52 (QSPI_SCLK), U4.6 (CLK)
/QSPI_SD0: U1.53 (QSPI_SD0), U4.5 (DI(IO0))
/QSPI_SD1: U1.55 (QSPI_SD1), U4.2 (DO(IO1))
/QSPI_SD2: U1.54 (QSPI_SD2), U4.3 (IO2)
/QSPI_SD3: U1.51 (QSPI_SD3), U4.7 (IO3)
/QSPI_SS_N: R29.1, R30.1, U1.56 (QSPI_SS_N), U4.1 (~CS)
/SWCLK: J2.2, U1.24 (SWCLK)
/SWDIO: J2.4, U1.25 (SWDIO)
/UART0_RX: J1.1, U1.3 (GPIO1)
/UART0_TX: J1.2, U1.2 (GPIO0)
/btn0: SW4.1, U1.17 (GPIO14)
GND: C1.2, C2.2, C3.2, C4.2, C5.2, C6.2, C7.2, C8.2, C31.2, C32.2, C33.2, C34.2, C35.2, C36.2, C37.2, C38.2, C39.2, C40.2, C41.2, C42.2, C43.2, C44.1, C45.2, C46.2, C47.1, C48.2, J1.3, J2.3, J3.1, J11.5 (GND), J11.6 (Shield), SW1.2, SW2.2, SW4.2, U1.19 (TESTEN), U1.57 (GND), U2.2 (GND), U3.11 (HPGND), U3.15 (AGND), U3.21 (MODE), U3.22 (CSB), U3.28 (DCGND), U4.4 (GND); also elsewhere on the board
unnamed: C2.1, R28.1, Y1.1
unnamed: C3.1, U1.20 (XIN), Y1.3
unnamed: C45.1, C46.1, U3.16 (VMID)
unnamed: J11.2 (D-), R35.2
unnamed: J11.3 (D+), R34.2
unnamed: R28.2, U1.21 (XOUT)
unnamed: R30.2, SW2.1
unnamed: R34.1, U1.47 (USB_DP)
unnamed: R35.1, U1.46 (USB_DM)
unnamed: TP1.1, U1.41 (GPIO29/ADC3)
unnamed: TP2.1, U1.40 (GPIO28/ADC2)
unnamed: TP3.1, U1.37 (GPIO25)
unnamed: TP4.1, U1.36 (GPIO24)
unnamed: TP5.1, U1.13 (GPIO10)
unnamed: TP6.1, U1.14 (GPIO11)
Vbus: J11.1 (VBUS); also elsewhere on the board
cv1: U1.38 (GPIO26/ADC0); also elsewhere on the board
cv2: U1.39 (GPIO27/ADC1); also elsewhere on the board
in_l: U3.20 (LLINEIN); also elsewhere on the board
in_r: U3.19 (RLINEIN); also elsewhere on the board
out_l: U3.12 (LOUT); also elsewhere on the board
out_r: U3.13 (ROUT); also elsewhere on the board

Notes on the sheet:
approx. 9.6MHz cutoff to prevent I2C interference.
Load only one FB

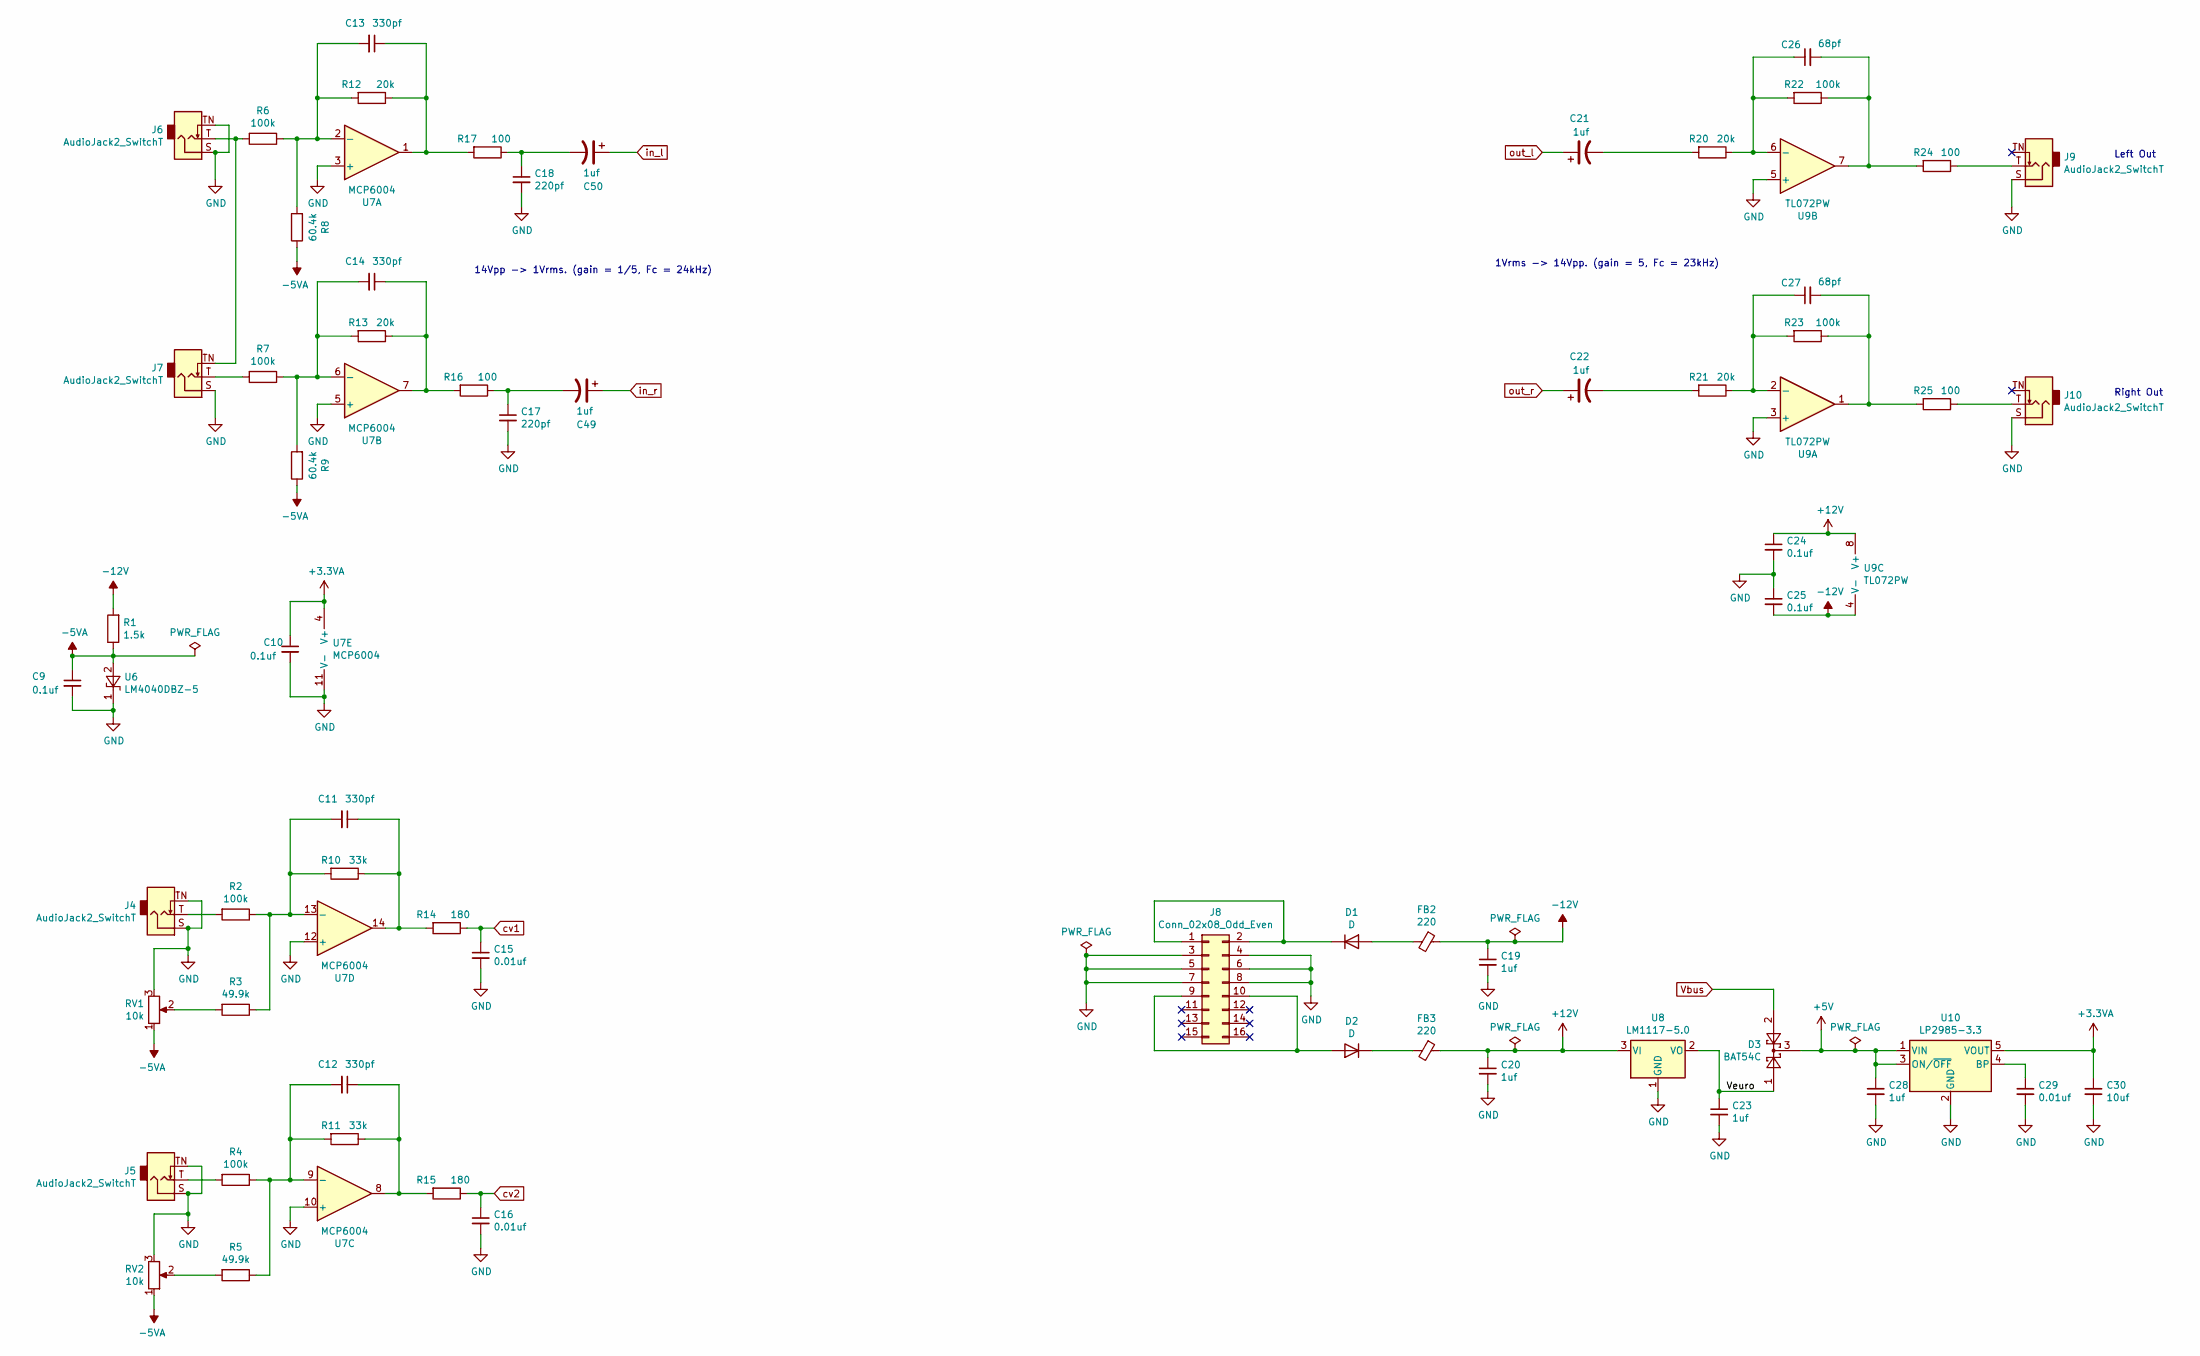
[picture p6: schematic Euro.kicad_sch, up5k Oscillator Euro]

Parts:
C9, C10, C24, C25: 0.1uf; C_0603
C11, C12, C13, C14: 330pf; C_0603
C15, C16, C29: 0.01uf; C_0603
C17, C18: 220pf; C_0603
C19, C20, C23, C28: 1uf; C_0603
C21, C22, C49, C50: 1uf; CP_Elec_4x5.3
C26, C27: 68pf; C_0603
C30: 10uf; C_0805
D1, D2: D; D_SMA
D3: BAT54C; SOT-23
FB2, FB3: 220; R_0805
J4, J5, J6, J7, J9, J10: AudioJack2_SwitchT; Jack_3.5mm_QingPu_WQP-PJ398SM_Vertical_CircularHoles
J8: Conn_02x08_Odd_Even; 5103308-3
R1: 1.5k; R_0603
R2, R4, R6, R7, R22, R23: 100k; R_0603
R3, R5: 49.9k; R_0603
R8, R9: 60.4k; R_0603
R10, R11: 33k; R_0603
R12, R13, R20, R21: 20k; R_0603
R14, R15: 180; R_0603
R16, R17, R24, R25: 100; R_0603
RV1, RV2: 10k; Potentiometer_TT_P0915N
U6: LM4040DBZ-5; SOT-23
U7: MCP6004; TSSOP-14_4.4x5mm_Pitch0.65mm
U8: LM1117-5.0; SOT-223-3_TabPin2
U9: TL072PW; TSSOP-8_4.4x3mm_Pitch0.65mm
U10: LP2985-3.3; SOT-23-5

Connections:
+3.3VA: C10.1, C30.1, U7.4 (V+), U10.5 (VOUT); also elsewhere on the board
+5V: C28.1, D3.3, U10.1 (VIN), U10.3 (ON/~OFF); also elsewhere on the board
+12V: C20.1, C24.1, FB3.1, U8.3 (VI), U9.8 (V+)
-5VA: C9.1, R1.1, R8.1, R9.1, RV1.1, RV2.1, U6.2 (A)
-12V: C19.1, C25.2, FB2.1, R1.2, U9.4 (V-)
/Sheet615690D3/Veuro: C23.1, D3.1, U8.2 (VO)
GND: C9.2, C10.2, C15.2, C16.2, C17.2, C18.2, C19.2, C20.2, C23.2, C24.2, C25.1, C28.2, C29.2, C30.2, J4.S, J4.TN, J5.S, J5.TN, J6.S, J6.TN, J7.S, J8.3, J8.4, J8.5, J8.6, J8.7, J8.8, J9.S, J10.S, RV1.3, RV2.3, U6.1 (K), U7.3 (+), U7.5 (+), U7.10 (+), U7.11 (V-), U7.12 (+), U8.1 (GND), U9.3 (+), U9.5 (+), U10.2 (GND); also elsewhere on the board
unnamed: C11.1, R10.1, R14.2, U7.14
unnamed: C11.2, R2.1, R3.1, R10.2, U7.13 (-)
unnamed: C12.1, R11.1, R15.2, U7.8
unnamed: C12.2, R4.1, R5.1, R11.2, U7.9 (-)
unnamed: C13.1, R12.1, R17.2, U7.1
unnamed: C13.2, R6.1, R8.2, R12.2, U7.2 (-)
unnamed: C14.1, R13.1, R16.2, U7.7
unnamed: C14.2, R7.1, R9.2, R13.2, U7.6 (-)
unnamed: C17.1, C49.2, R16.1
unnamed: C18.1, C50.2, R17.1
unnamed: C21.2, R20.2
unnamed: C22.2, R21.2
unnamed: C26.1, R20.1, R22.2, U9.6 (-)
unnamed: C26.2, R22.1, R24.2, U9.7
unnamed: C27.1, R21.1, R23.2, U9.2 (-)
unnamed: C27.2, R23.1, R25.2, U9.1
unnamed: C29.1, U10.4 (BP)
unnamed: D1.1 (K), J8.1, J8.2
unnamed: D1.2 (A), FB2.2
unnamed: D2.1 (K), FB3.2
unnamed: D2.2 (A), J8.9, J8.10
unnamed: J4.T, R2.2
unnamed: J5.T, R4.2
unnamed: J6.T, J7.TN, R6.2
unnamed: J7.T, R7.2
unnamed: J9.T, R24.1
unnamed: J10.T, R25.1
unnamed: R3.2, RV1.2
unnamed: R5.2, RV2.2
Vbus: D3.2; also elsewhere on the board
cv1: C15.1, R14.1; also elsewhere on the board
cv2: C16.1, R15.1; also elsewhere on the board
in_l: C50.1; also elsewhere on the board
in_r: C49.1; also elsewhere on the board
out_l: C21.1; also elsewhere on the board
out_r: C22.1; also elsewhere on the board

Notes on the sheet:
Right Out
14Vpp -> 1Vrms. (gain = 1/5, Fc = 24kHz)
1Vrms -> 14Vpp. (gain = 5, Fc = 23kHz)
Left Out

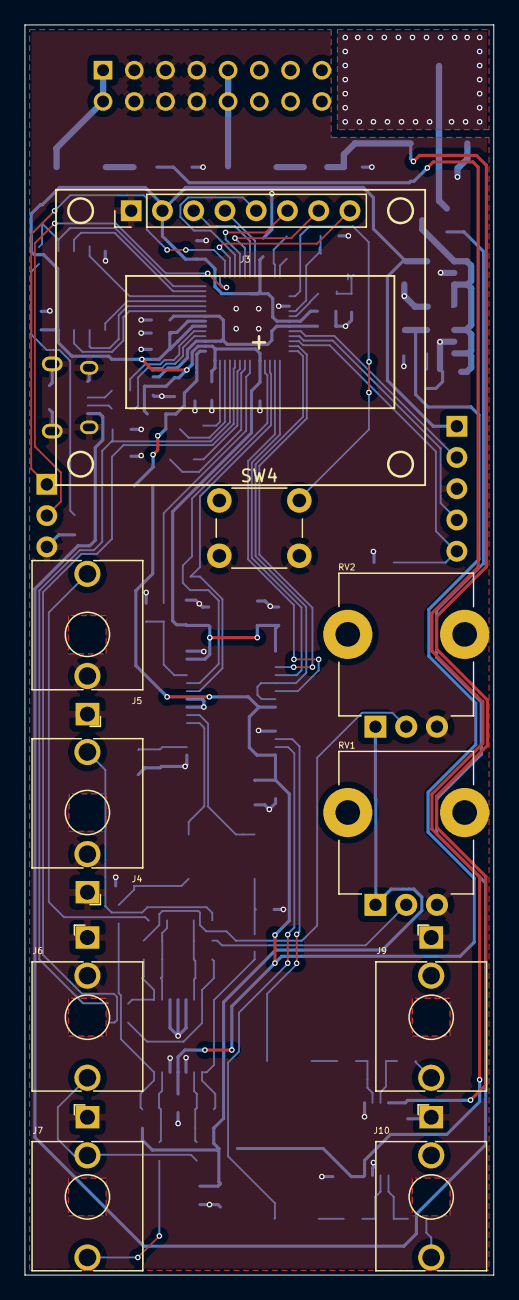
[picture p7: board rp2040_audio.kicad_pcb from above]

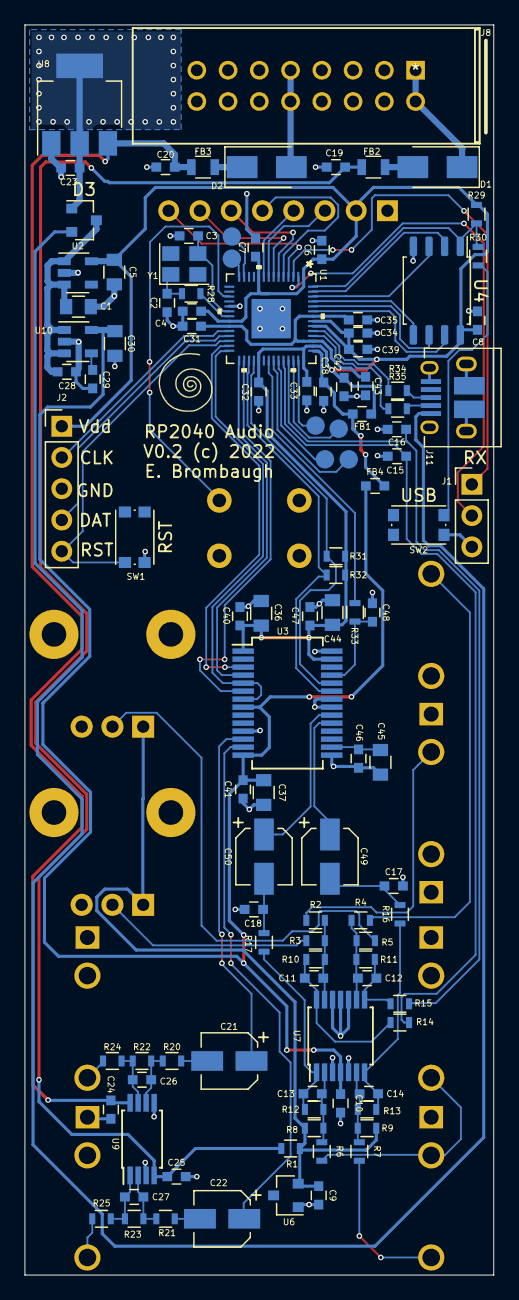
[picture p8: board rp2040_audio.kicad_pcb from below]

Board: 2 copper layers, 38.1 x 101.6 mm, 121 parts (111 on the bottom side), 87 nets.

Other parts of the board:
Ref**: Val**; avatar_small

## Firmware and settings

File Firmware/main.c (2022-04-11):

/*
 * main.c - part of rp2040_audio. Includes WM8731 codec + LCD.
 * WM8731 requires full-duplex operation so the generic I2S
 * output driver provided for RPi RP2040 will not work for it.
 * 03-28-22 E. Brombaugh
 */

#include <stdio.h>
#include "main.h"
#include "pico/unique_id.h"
#include "i2s_fulldup.h"
#include "wm8731.h"
#include "audio.h"
#include "st7735.h"
#include "button.h"
#include "adc.h"
#include "gfx.h"
#include "menu.h"
#include "splash.h"

/* build version in simple format */
const char *fwVersionStr = "V0.2";

/* build time */
const char *bdate = __DATE__;
const char *btime = __TIME__;

/*
 * main prog
 */
int main()
{
	int32_t i;
	uint16_t prog = 255;
	char textbuf[32];
	pico_unique_board_id_t id_out;
	
	/* startup msg */
    stdio_init_all();
	printf("\n\nRP2040_Audio - Audio DSP module %s starting\n\r", fwVersionStr);
	printf("CHIP_ID: 0x%08X\n\r", *(volatile uint32_t *)(SYSINFO_BASE));
	printf("BOARD_ID: 0x");
	pico_get_unique_board_id(&id_out);
	for(i=0;i<PICO_UNIQUE_BOARD_ID_SIZE_BYTES;i++)
		printf("%02X", id_out.id[i]);
	printf("\n");
	printf("Build Date: %s\n\r", bdate);
	printf("Build Time: %s\n\r", btime);
	printf("\n");

	/* button input */
	button_init();
	printf("Button Initialized\n");
	
	/* init codec */
	WM8731_Init();
	printf("Codec Initialized\n");
	
	/* init ADC for cvs */
	ADC_init();
	printf("ADC Initialized\n");
	
	/* init Audio */
	Audio_Init();
	printf("Audio Initialized\n");
	
	/* init Audio */
	init_i2s_fulldup();
	printf("I2S Initialized\n");
	
	/* Init LCD */
	gfx_init(&ST7735_drvr);
	gfx_bitblt(0, 0, 160, 80, (uint16_t *)splash_png_565);
	gfx_set_forecolor(GFX_BLACK);
	gfx_set_backcolor(0xc7def6);
	gfx_drawstrctr(120, 20, "RP2040");
	gfx_drawstrctr(120, 30, "Audio");
	gfx_drawstrctr(120, 40, (char *)fwVersionStr);
	gfx_set_forecolor(GFX_WHITE);
	gfx_set_backcolor(GFX_BLACK);
	ST7735_setBacklight(1);
	printf("GFX Initialized\n");
	
	/* splash delay */
	printf("Splash delay\n");
	sleep_ms(3000);
	
	/* init menu */
    printf("Init menu\n");
	menu_init();
	
	/* loop here forever */
	printf("Looping...\n");
    while(true)
    {
		//printf("%1d 0x%03X 0x%03X\r", button_get(), ADC_val[0], ADC_val[1]);
		menu_update();
	}

	/* should never get here */
	return 0;
}

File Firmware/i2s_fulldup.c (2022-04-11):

/*
 * i2s_fulldup.c - PIO-based full-duplex I2S for RP2040
 * 12-19-21 E. Brombaugh
 *
 * Based on original ideas from
 * https://gist.github.com/jonbro/3da573315f066be8ea390db39256f9a7
 * and the pico-extras library.
 */

#include <stdio.h>
#include <string.h>
#include "i2s_fulldup.h"
#include "hardware/dma.h"
#include "hardware/irq.h"
#include "hardware/pio.h"
#include "hardware/structs/clocks.h"
#include "hardware/clocks.h"
#include "pico/multicore.h"
#include "i2s_fulldup.pio.h"
#include "audio.h"

/* uncomment this to run audio processing on core 1 */
#define MULTICORE

/* I2S PIO has L+R (Frames) in 32-bits */
#define FRAMES_PER_BUFFER (BUFSZ/2)

/* I2S comes out on these pins */
#if 0
/* HW V0.1 */
#define I2S_DO_PIN 18		// data out
#define I2S_DI_PIN 17		// data in
#define I2S_CLK_PIN_BASE 24	// BCLK, LRCK (Temporarily on TP3, TP4)
#define I2S_MCLK_PIN 23		// MCLK

#define IN_DIAG_PIN 10		// TP5
#define OUT_DIAG_PIN 11		// TP6
#else
/* HW V0.2 */
#define I2S_DO_PIN 18		// data out
#define I2S_DI_PIN 19		// data in
#define I2S_CLK_PIN_BASE 16	// BCLK, LRCK
#define I2S_MCLK_PIN 23		// MCLK

#define IN_DIAG_PIN 10		// TP5
#define OUT_DIAG_PIN 11		// TP6
#endif

/* resources we use */
PIO pio;
uint sm;
uint dma_chan_input, dma_chan_output;
uint ib_idx, ob_idx;
uint32_t input_buf[2*FRAMES_PER_BUFFER], output_buf[2*FRAMES_PER_BUFFER],
	xfer_buf[FRAMES_PER_BUFFER];

/*
 * IRQ0 handler - used only for I2S input
 * ATM this is not double-buffered, but it would be prudent to
 * do so if adding code to compute the next buffer.
 */
void dma_input_handler(void)
{
	gpio_put(IN_DIAG_PIN, 1);
	
	/* Clear IRQ for I2S input */
    dma_irqn_acknowledge_channel(DMA_IRQ_0, dma_chan_input);
	
	/* reset write address to start of next buffer */
	ib_idx ^= 1;
	dma_channel_set_write_addr(dma_chan_input,
		&input_buf[ib_idx*FRAMES_PER_BUFFER],
		true
	);
	
	/* start next transfer sequence */
	dma_channel_start(dma_chan_input);
	
#if 0
	/* save previous buffer */
	memcpy(xfer_buf, &input_buf[ib_idx*FRAMES_PER_BUFFER],
		FRAMES_PER_BUFFER*sizeof(uint32_t));
#else
	/* do audio processing on previous buffer */
	Audio_Proc((int16_t *)xfer_buf,
	(int16_t *)&input_buf[(ib_idx^1)*FRAMES_PER_BUFFER],
		2*FRAMES_PER_BUFFER);
#endif

	gpio_put(IN_DIAG_PIN, 0);
}

/*
 * IRQ1 handler - used only for I2S output
 * ATM this is not double-buffered, but it would be prudent to
 * do so if adding code to compute the next buffer.
 */
void dma_output_handler()
{
	gpio_put(OUT_DIAG_PIN, 1);
	
	/* Clear IRQ for I2S output */
    dma_irqn_acknowledge_channel(DMA_IRQ_1, dma_chan_output);
	
	/* reset read address to start of next buffer */
	ob_idx ^= 1;
	dma_channel_set_read_addr(dma_chan_output,
		&output_buf[ob_idx*FRAMES_PER_BUFFER],
		true
	);
	
	/* start next transfer sequence */
	dma_channel_start(dma_chan_output);
	
	/* fill previous buffer with new data */
#if 1
	/* loopback */
	memcpy(&output_buf[ob_idx*FRAMES_PER_BUFFER], xfer_buf,
		FRAMES_PER_BUFFER*sizeof(uint32_t));
#else
	/* do audio processing */
	Audio_Proc((int16_t *)&output_buf[ob_idx*FRAMES_PER_BUFFER],
		(int16_t *)xfer_buf,
		2*FRAMES_PER_BUFFER);
#endif
	
	gpio_put(OUT_DIAG_PIN, 0);
}

#ifdef MULTICORE
/*
 * entry point for 2nd core to start running
 */
void core1_entry()
{
	/* enable IRQ handler for dma input */
    irq_set_exclusive_handler(DMA_IRQ_0, dma_input_handler);
    irq_set_enabled(DMA_IRQ_0, true);
	

	/* enable IRQ handler for dma output */
    irq_set_exclusive_handler(DMA_IRQ_1, dma_output_handler);
    irq_set_enabled(DMA_IRQ_1, true);
	
	/* enable multicore lockout */
	multicore_lockout_victim_init();

	/* loop here waiting for IRQs */
	while(1)
	{
		Audio_Fore();
	}
}
#endif

/*
 * initialize the I2S processing
 */
void init_i2s_fulldup(void)
{
	int32_t i;
	int16_t *obuf = (int16_t *)output_buf;
	int16_t *ibuf = (int16_t *)input_buf;
	
	/* clear buffers */
	for(i=0;i<2*FRAMES_PER_BUFFER;i++)
	{
		*ibuf++ = 0;
		*ibuf++ = 0;
		*obuf++ = 0;
		*obuf++ = 0;
	}

	/* diag GPIO */
	gpio_init(IN_DIAG_PIN);
	gpio_set_dir(IN_DIAG_PIN, GPIO_OUT);
	gpio_init(OUT_DIAG_PIN);
	gpio_set_dir(OUT_DIAG_PIN, GPIO_OUT);

    /* set up PIO */
    pio = pio0;
    uint offset = pio_add_program(pio, &i2s_fulldup_program);
    printf("loaded program at offset: %i\n", offset);
    sm = pio_claim_unused_sm(pio, true);
    printf("claimed sm: %i\n", sm);
	
	/* compute PIO divider for desired sample rate */
    uint32_t system_clock_frequency = clock_get_hz(clk_sys);
    assert(system_clock_frequency < 0x40000000);
    printf("System clock %u Hz\n", (uint) system_clock_frequency);
    uint32_t sample_freq = 48000;
    printf("Target sample freq %d\n", sample_freq);
    uint32_t divider = system_clock_frequency * 2 / sample_freq; // avoid arithmetic overflow
    divider = divider & ~(0x1ff); // mask off bottom 9 for exact MCLK/BCLK ratio of 4.0
    assert(divider < 0x1000000);
    printf("PIO clock divider 0x%x/256\n", divider);
	printf("Actual sample freq = %d\n", 2 * system_clock_frequency / divider);
	
	/* set up the PIO and divider */
    i2s_fulldup_program_init(
		pio,
		sm,
		offset,
		I2S_DO_PIN,
		I2S_DI_PIN,
		I2S_CLK_PIN_BASE
	);
    pio_sm_set_clkdiv_int_frac(pio, sm, divider >> 8u, divider & 0xffu);
	
	/* generate an MCLK on GPIO at 8x BCLK (256x LRCK) */
	gpio_set_function(I2S_MCLK_PIN, GPIO_FUNC_GPCK);
	clock_gpio_init(I2S_MCLK_PIN, CLOCKS_CLK_GPOUT1_CTRL_AUXSRC_VALUE_CLK_SYS, divider>>9);
	printf("MCLK at %d Hz\n", system_clock_frequency/(divider>>9));
	
    /* configure dma channel for input */
	ib_idx = 0;
    dma_chan_input = dma_claim_unused_channel(true);
	printf("DMA input using chl %d\n", dma_chan_input);
    dma_channel_config c = dma_channel_get_default_config(dma_chan_input);
    channel_config_set_read_increment(&c,false);
    channel_config_set_write_increment(&c,true);
    channel_config_set_dreq(&c,pio_get_dreq(pio,sm,false));
    channel_config_set_transfer_data_size(&c, DMA_SIZE_32);

    dma_channel_configure(
        dma_chan_input,
        &c,
        input_buf, 			// Destination pointer
        &pio->rxf[sm], 		// Source pointer
        FRAMES_PER_BUFFER, // Number of transfers
        true				// Start immediately
    );
    dma_channel_set_irq0_enabled(dma_chan_input, true);
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

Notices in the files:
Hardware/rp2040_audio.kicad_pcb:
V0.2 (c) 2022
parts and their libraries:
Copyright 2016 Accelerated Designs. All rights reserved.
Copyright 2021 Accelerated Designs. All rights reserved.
